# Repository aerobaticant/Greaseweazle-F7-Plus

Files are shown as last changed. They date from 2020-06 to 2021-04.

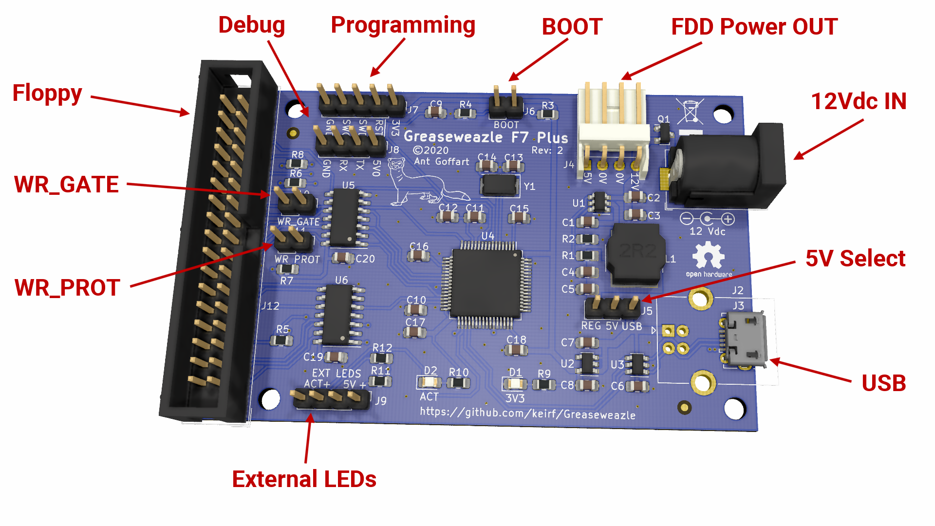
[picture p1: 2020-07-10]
Greaseweazle_F7_Plus_V2_White_Labelled.png

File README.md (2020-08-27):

# Greaseweazle-F7-Plus
My board design for [Keir Fraser's Greaseweazle](https://github.com/keirf/Greaseweazle).

The differences between this design and the original F7 are:

  * PCB 80mm x 50mm, KryoFlux form factor.
  * Added stronger buffers for driving 5.25" drives with higher current pull-up resistors.
  * Integrated 5V switching regulator, so only a single 12V supply is required for drives needing both rails.
  * Choice of full-size or micro USB connector.
  * USB ESD (electro-static discharge) protection.
  * Connections for external LEDs, for use if fitting the board in an enclosure.
  * Jumper link to select write protection by default.
  * Jumper link to disconnect WR_GATE for physical hardware level write protection.

This repository has only just been created.

Please check out the [Wiki](https://github.com/aerobaticant/Greaseweazle-F7-Plus/wiki) (under construction).

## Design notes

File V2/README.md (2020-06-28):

This is the folder containing the source files for my Greaseweazle V2 Plus board

Please note that this design is released using the Open Hardware licence.
https://www.oshwa.org/definition/

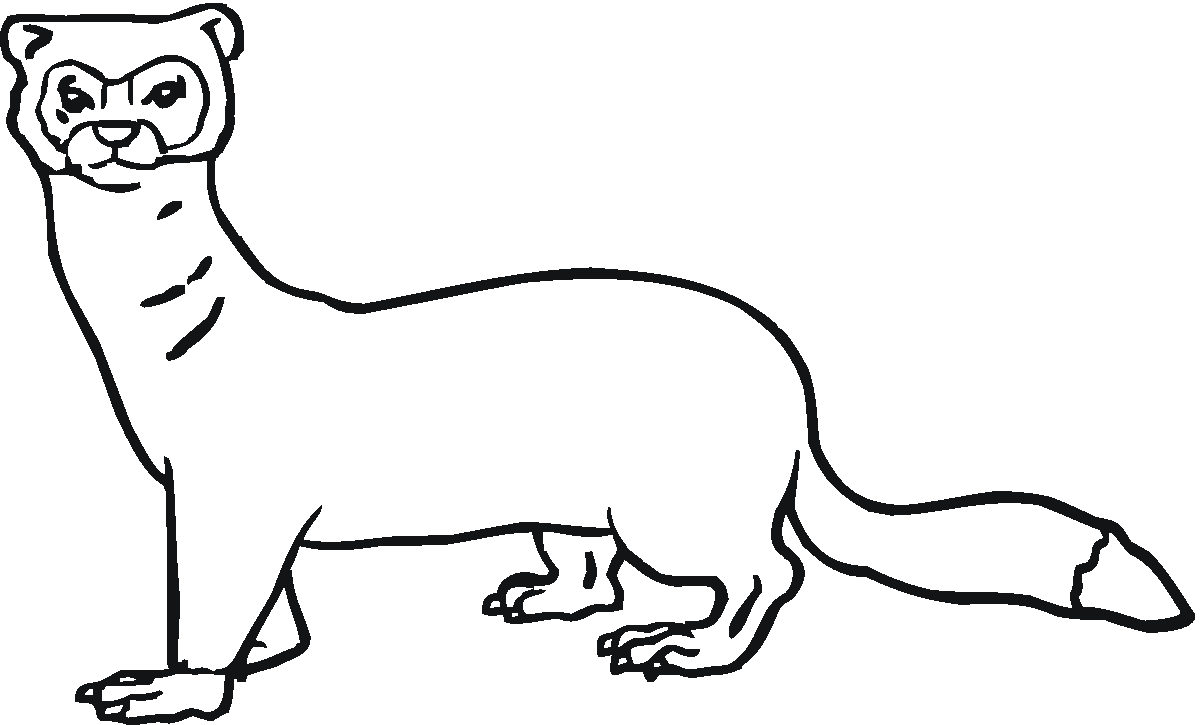
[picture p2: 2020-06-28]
V2/weasle_clipart.png

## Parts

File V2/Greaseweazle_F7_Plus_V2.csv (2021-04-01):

Source: | C:\Projects\KiCad\Greaseweazle_F7_Plus_V2\Greaseweazle_F7_Plus_V2.sch
Date: | 18/06/2020 10:20:13
Tool: | Eeschema (5.1.5)-3
Generator: | C:\Program Files\KiCad\bin\scripting\plugins/bom_csv_grouped_by_value.py
Component Count: | 62
Individual Components:
Item | Qty | Reference(s) | Value | LibPart | Footprint | Datasheet
 |  | C1 | 100N | Device:C_Small | Capacitor_SMD:C_0805_2012Metric_Pad1.15x1.40mm_HandSolder | ~
 |  | C2 | 10U | Device:C_Small | Capacitor_SMD:C_0805_2012Metric_Pad1.15x1.40mm_HandSolder | ~
 |  | C3 | 10U | Device:C_Small | Capacitor_SMD:C_0805_2012Metric_Pad1.15x1.40mm_HandSolder | ~
 |  | C4 | 22U | Device:C_Small | Capacitor_SMD:C_0805_2012Metric_Pad1.15x1.40mm_HandSolder | ~
 |  | C5 | 22U | Device:C_Small | Capacitor_SMD:C_0805_2012Metric_Pad1.15x1.40mm_HandSolder | ~
 |  | C6 | 100N | Device:C_Small | Capacitor_SMD:C_0805_2012Metric_Pad1.15x1.40mm_HandSolder | ~
 |  | C7 | 1U0 | Device:C_Small | Capacitor_SMD:C_0805_2012Metric_Pad1.15x1.40mm_HandSolder | ~
 |  | C8 | 1U0 | Device:C_Small | Capacitor_SMD:C_0805_2012Metric_Pad1.15x1.40mm_HandSolder | ~
 |  | C9 | 100N | Device:C_Small | Capacitor_SMD:C_0805_2012Metric_Pad1.15x1.40mm_HandSolder | ~
 |  | C10 | 10U | Device:C_Small | Capacitor_SMD:C_0805_2012Metric_Pad1.15x1.40mm_HandSolder | ~
 |  | C11 | 1U0 | Device:C_Small | Capacitor_SMD:C_0805_2012Metric_Pad1.15x1.40mm_HandSolder | ~
 |  | C12 | 100N | Device:C_Small | Capacitor_SMD:C_0805_2012Metric_Pad1.15x1.40mm_HandSolder | ~
 |  | C13 | 27P | Device:C_Small | Capacitor_SMD:C_0805_2012Metric_Pad1.15x1.40mm_HandSolder | ~
 |  | C14 | 27P | Device:C_Small | Capacitor_SMD:C_0805_2012Metric_Pad1.15x1.40mm_HandSolder | ~
 |  | C15 | 100N | Device:C_Small | Capacitor_SMD:C_0805_2012Metric_Pad1.15x1.40mm_HandSolder | ~
 |  | C16 | 100N | Device:C_Small | Capacitor_SMD:C_0805_2012Metric_Pad1.15x1.40mm_HandSolder | ~
 |  | C17 | 100N | Device:C_Small | Capacitor_SMD:C_0805_2012Metric_Pad1.15x1.40mm_HandSolder | ~
 |  | C18 | 100N | Device:C_Small | Capacitor_SMD:C_0805_2012Metric_Pad1.15x1.40mm_HandSolder | ~
 |  | C19 | 100N | Device:C_Small | Capacitor_SMD:C_0805_2012Metric_Pad1.15x1.40mm_HandSolder | ~
 |  | C20 | 100N | Device:C_Small | Capacitor_SMD:C_0805_2012Metric_Pad1.15x1.40mm_HandSolder | ~
 |  | D1 | GREEN | Device:LED_Small | LED_SMD:LED_0805_2012Metric_Pad1.15x1.40mm_HandSolder | ~
 |  | D2 | GREEN | Device:LED_Small | LED_SMD:LED_0805_2012Metric_Pad1.15x1.40mm_HandSolder | ~
 |  | FID1 | Fiducial | Mechanical:Fiducial | Fiducial:Fiducial_1mm_Mask2mm | ~
 |  | FID2 | Fiducial | Mechanical:Fiducial | Fiducial:Fiducial_1mm_Mask2mm | ~
 |  | H1 | M3 | Mechanical:MountingHole | MountingHole:MountingHole_3mm | ~
 |  | H2 | M3 | Mechanical:MountingHole | MountingHole:MountingHole_3mm | ~
 |  | H3 | M3 | Mechanical:MountingHole | MountingHole:MountingHole_3mm | ~
 |  | H4 | M3 | Mechanical:MountingHole | MountingHole:MountingHole_3mm | ~
 |  | J1 | Wurth 694106301002 | Connector:Barrel_Jack_Switch | Connector_BarrelJack:BarrelJack_Horizontal | ~
 |  | J2 | USB_B | Connector:USB_B | Connector_USB:USB_B_OST_USB-B1HSxx_Horizontal | ~
 |  | J3 | Molex 105017-1001 | Connector:USB_B_Micro | Connector_USB:USB_Micro-B_Molex-105017-0001 | ~
 |  | J4 | TE EI 171826-4 | Connector_Generic:Conn_01x04 | AmberTronic:TE_171826-4_1x4_P2.50mm_Horizontal | ~
 |  | J5 | PIN1X3 | Connector_Generic:Conn_01x03 | Connector_PinHeader_2.54mm:PinHeader_1x03_P2.54mm_Vertical | ~
 |  | J6 | PIN1X2 | Connector_Generic:Conn_01x02 | Connector_PinHeader_2.54mm:PinHeader_1x02_P2.54mm_Vertical | ~
 |  | J7 | PIN1X5 | Connector_Generic:Conn_01x05 | Connector_PinHeader_2.54mm:PinHeader_1x05_P2.54mm_Vertical | ~
 |  | J8 | PIN1X4 | Connector_Generic:Conn_01x04 | Connector_PinHeader_2.54mm:PinHeader_1x04_P2.54mm_Vertical | ~
 |  | J9 | PIN1X4 | Connector_Generic:Conn_01x04 | Connector_PinHeader_2.54mm:PinHeader_1x04_P2.54mm_Vertical | ~
 |  | J10 | PIN1X2 | Connector_Generic:Conn_01x02 | Connector_PinHeader_2.54mm:PinHeader_1x02_P2.54mm_Vertical | ~
 |  | J11 | PIN1X2 | Connector_Generic:Conn_01x02 | Connector_PinHeader_2.54mm:PinHeader_1x02_P2.54mm_Vertical | ~
 |  | J12 | IDC Box Header | Connector_Generic:Conn_02x17_Odd_Even | Connector_IDC:IDC-Header_2x17_P2.54mm_Vertical | ~
 |  | L1 | SRN8040TA-4R7 | Device:L_Small | Inductor_SMD:L_Bourns_SRN8040TA | ~
 |  | LOGO1 | OSHW Logo | Graphic:Logo_Open_Hardware_Small | Symbol:OSHW-Logo2_7.3x6mm_SilkScreen | ~
 |  | Q1 | Si2393DS | Device:Q_PMOS_GSD | Package_TO_SOT_SMD:SOT-23 | ~
 |  | R1 | 54K9 | Device:R_Small | Resistor_SMD:R_0805_2012Metric_Pad1.15x1.40mm_HandSolder | ~
 |  | R2 | 10K0 | Device:R_Small | Resistor_SMD:R_0805_2012Metric_Pad1.15x1.40mm_HandSolder | ~
 |  | R3 | 1K0 | Device:R_Small | Resistor_SMD:R_0805_2012Metric_Pad1.15x1.40mm_HandSolder | ~
 |  | R4 | 10K0 | Device:R_Small | Resistor_SMD:R_0805_2012Metric_Pad1.15x1.40mm_HandSolder | ~
 |  | R5 | 1K0 | Device:R_Small | Resistor_SMD:R_0805_2012Metric_Pad1.15x1.40mm_HandSolder | ~
 |  | R6 | 1K0 | Device:R_Small | Resistor_SMD:R_0805_2012Metric_Pad1.15x1.40mm_HandSolder | ~
 |  | R7 | 1K0 | Device:R_Small | Resistor_SMD:R_0805_2012Metric_Pad1.15x1.40mm_HandSolder | ~
 |  | R8 | 1K0 | Device:R_Small | Resistor_SMD:R_0805_2012Metric_Pad1.15x1.40mm_HandSolder | ~
 |  | R9 | 330R | Device:R_Small | Resistor_SMD:R_0805_2012Metric_Pad1.15x1.40mm_HandSolder | ~
 |  | R10 | 330R | Device:R_Small | Resistor_SMD:R_0805_2012Metric_Pad1.15x1.40mm_HandSolder | ~
 |  | R11 | 560R | Device:R_Small | Resistor_SMD:R_0805_2012Metric_Pad1.15x1.40mm_HandSolder | ~
 |  | R12 | 560R | Device:R_Small | Resistor_SMD:R_0805_2012Metric_Pad1.15x1.40mm_HandSolder | ~
 |  | U1 | TPS562201DDC | Regulator_Switching:TPS562200 | Package_TO_SOT_SMD:SOT-23-6 | http://www.ti.com/lit/ds/symlink/tps563200.pdf
 |  | U2 | TLV75533PDBV | Regulator_Linear:TLV75533PDBV | Package_TO_SOT_SMD:SOT-23-5 | http://www.ti.com/lit/ds/symlink/tlv755p.pdf
 |  | U3 | USBLC6-2SC6 | Power_Protection:USBLC6-2SC6 | Package_TO_SOT_SMD:SOT-23-6 | http://www2.st.com/resource/en/datasheet/CD00050750.pdf
 |  | U4 | STM32F730R8T6 | MCU_ST_STM32F7:STM32F732RETx | Package_QFP:LQFP-64_10x10mm_P0.5mm | http://www.st.com/st-web-ui/static/active/en/resource/technical/document/datasheet/DM00330507.pdf
 |  | U5 | 74LS07 | 74xx:74LS07 | Package_SO:SOIC-14_3.9x8.7mm_P1.27mm | www.ti.com/lit/ds/symlink/sn74ls07.pdf
 |  | U6 | 74LS07 | 74xx:74LS07 | Package_SO:SOIC-14_3.9x8.7mm_P1.27mm | www.ti.com/lit/ds/symlink/sn74ls07.pdf
 |  | Y1 | 8.000MHz | Device:Crystal_Small | Crystal:Crystal_SMD_5032-2Pin_5.0x3.2mm | ~
Collated Components:
Item | Qty | Reference(s) | Value | LibPart | Footprint | Datasheet
1 | 10 | C1, C6, C9, C12, C15, C16, C17, C18, C19, C20 | 100N | Device:C_Small | Capacitor_SMD:C_0805_2012Metric_Pad1.15x1.40mm_HandSolder | ~
2 | 3 | C2, C3, C10 | 10U | Device:C_Small | Capacitor_SMD:C_0805_2012Metric_Pad1.15x1.40mm_HandSolder | ~
3 | 2 | C4, C5 | 22U | Device:C_Small | Capacitor_SMD:C_0805_2012Metric_Pad1.15x1.40mm_HandSolder | ~
4 | 3 | C7, C8, C11 | 1U0 | Device:C_Small | Capacitor_SMD:C_0805_2012Metric_Pad1.15x1.40mm_HandSolder | ~
5 | 2 | C13, C14 | 27P | Device:C_Small | Capacitor_SMD:C_0805_2012Metric_Pad1.15x1.40mm_HandSolder | ~
6 | 2 | D1, D2 | GREEN | Device:LED_Small | LED_SMD:LED_0805_2012Metric_Pad1.15x1.40mm_HandSolder | ~
7 | 2 | FID1, FID2 | Fiducial | Mechanical:Fiducial | Fiducial:Fiducial_1mm_Mask2mm | ~
8 | 4 | H1, H2, H3, H4 | M3 | Mechanical:MountingHole | MountingHole:MountingHole_3mm | ~
9 | 1 | J1 | Wurth 694106301002 | Connector:Barrel_Jack_Switch | Connector_BarrelJack:BarrelJack_Horizontal | ~
10 | 1 | J2 | USB_B | Connector:USB_B | Connector_USB:USB_B_OST_USB-B1HSxx_Horizontal | ~
11 | 1 | J3 | Molex 105017-1001 | Connector:USB_B_Micro | Connector_USB:USB_Micro-B_Molex-105017-0001 | ~
12 | 1 | J4 | TE EI 171826-4 | Connector_Generic:Conn_01x04 | AmberTronic:TE_171826-4_1x4_P2.50mm_Horizontal | ~
13 | 1 | J5 | PIN1X3 | Connector_Generic:Conn_01x03 | Connector_PinHeader_2.54mm:PinHeader_1x03_P2.54mm_Vertical | ~
14 | 3 | J6, J10, J11 | PIN1X2 | Connector_Generic:Conn_01x02 | Connector_PinHeader_2.54mm:PinHeader_1x02_P2.54mm_Vertical | ~
15 | 1 | J7 | PIN1X5 | Connector_Generic:Conn_01x05 | Connector_PinHeader_2.54mm:PinHeader_1x05_P2.54mm_Vertical | ~
16 | 2 | J8, J9 | PIN1X4 | Connector_Generic:Conn_01x04 | Connector_PinHeader_2.54mm:PinHeader_1x04_P2.54mm_Vertical | ~
17 | 1 | J12 | IDC Box Header | Connector_Generic:Conn_02x17_Odd_Even | Connector_IDC:IDC-Header_2x17_P2.54mm_Vertical | ~
18 | 1 | L1 | SRN8040TA-4R7 | Device:L_Small | Inductor_SMD:L_Bourns_SRN8040TA | ~
19 | 1 | LOGO1 | OSHW Logo | Graphic:Logo_Open_Hardware_Small | Symbol:OSHW-Logo2_7.3x6mm_SilkScreen | ~
20 | 1 | Q1 | Si2393DS | Device:Q_PMOS_GSD | Package_TO_SOT_SMD:SOT-23 | ~
21 | 1 | R1 | 54K9 | Device:R_Small | Resistor_SMD:R_0805_2012Metric_Pad1.15x1.40mm_HandSolder | ~
22 | 2 | R2, R4 | 10K0 | Device:R_Small | Resistor_SMD:R_0805_2012Metric_Pad1.15x1.40mm_HandSolder | ~
23 | 5 | R3, R5, R6, R7, R8 | 1K0 | Device:R_Small | Resistor_SMD:R_0805_2012Metric_Pad1.15x1.40mm_HandSolder | ~
24 | 2 | R9, R10 | 330R | Device:R_Small | Resistor_SMD:R_0805_2012Metric_Pad1.15x1.40mm_HandSolder | ~
25 | 2 | R11, R12 | 560R | Device:R_Small | Resistor_SMD:R_0805_2012Metric_Pad1.15x1.40mm_HandSolder | ~
26 | 1 | U1 | TPS562201DDC | Regulator_Switching:TPS562200 | Package_TO_SOT_SMD:SOT-23-6 | http://www.ti.com/lit/ds/symlink/tps563200.pdf
27 | 1 | U2 | TLV75533PDBV | Regulator_Linear:TLV75533PDBV | Package_TO_SOT_SMD:SOT-23-5 | http://www.ti.com/lit/ds/symlink/tlv755p.pdf
28 | 1 | U3 | USBLC6-2SC6 | Power_Protection:USBLC6-2SC6 | Package_TO_SOT_SMD:SOT-23-6 | http://www2.st.com/resource/en/datasheet/CD00050750.pdf
29 | 1 | U4 | STM32F730R8T6 | MCU_ST_STM32F7:STM32F732RETx | Package_QFP:LQFP-64_10x10mm_P0.5mm | http://www.st.com/st-web-ui/static/active/en/resource/technical/document/datasheet/DM00330507.pdf
30 | 2 | U5, U6 | 74LS07 | 74xx:74LS07 | Package_SO:SOIC-14_3.9x8.7mm_P1.27mm | www.ti.com/lit/ds/symlink/sn74ls07.pdf
31 | 1 | Y1 | 8.000MHz | Device:Crystal_Small | Crystal:Crystal_SMD_5032-2Pin_5.0x3.2mm | ~

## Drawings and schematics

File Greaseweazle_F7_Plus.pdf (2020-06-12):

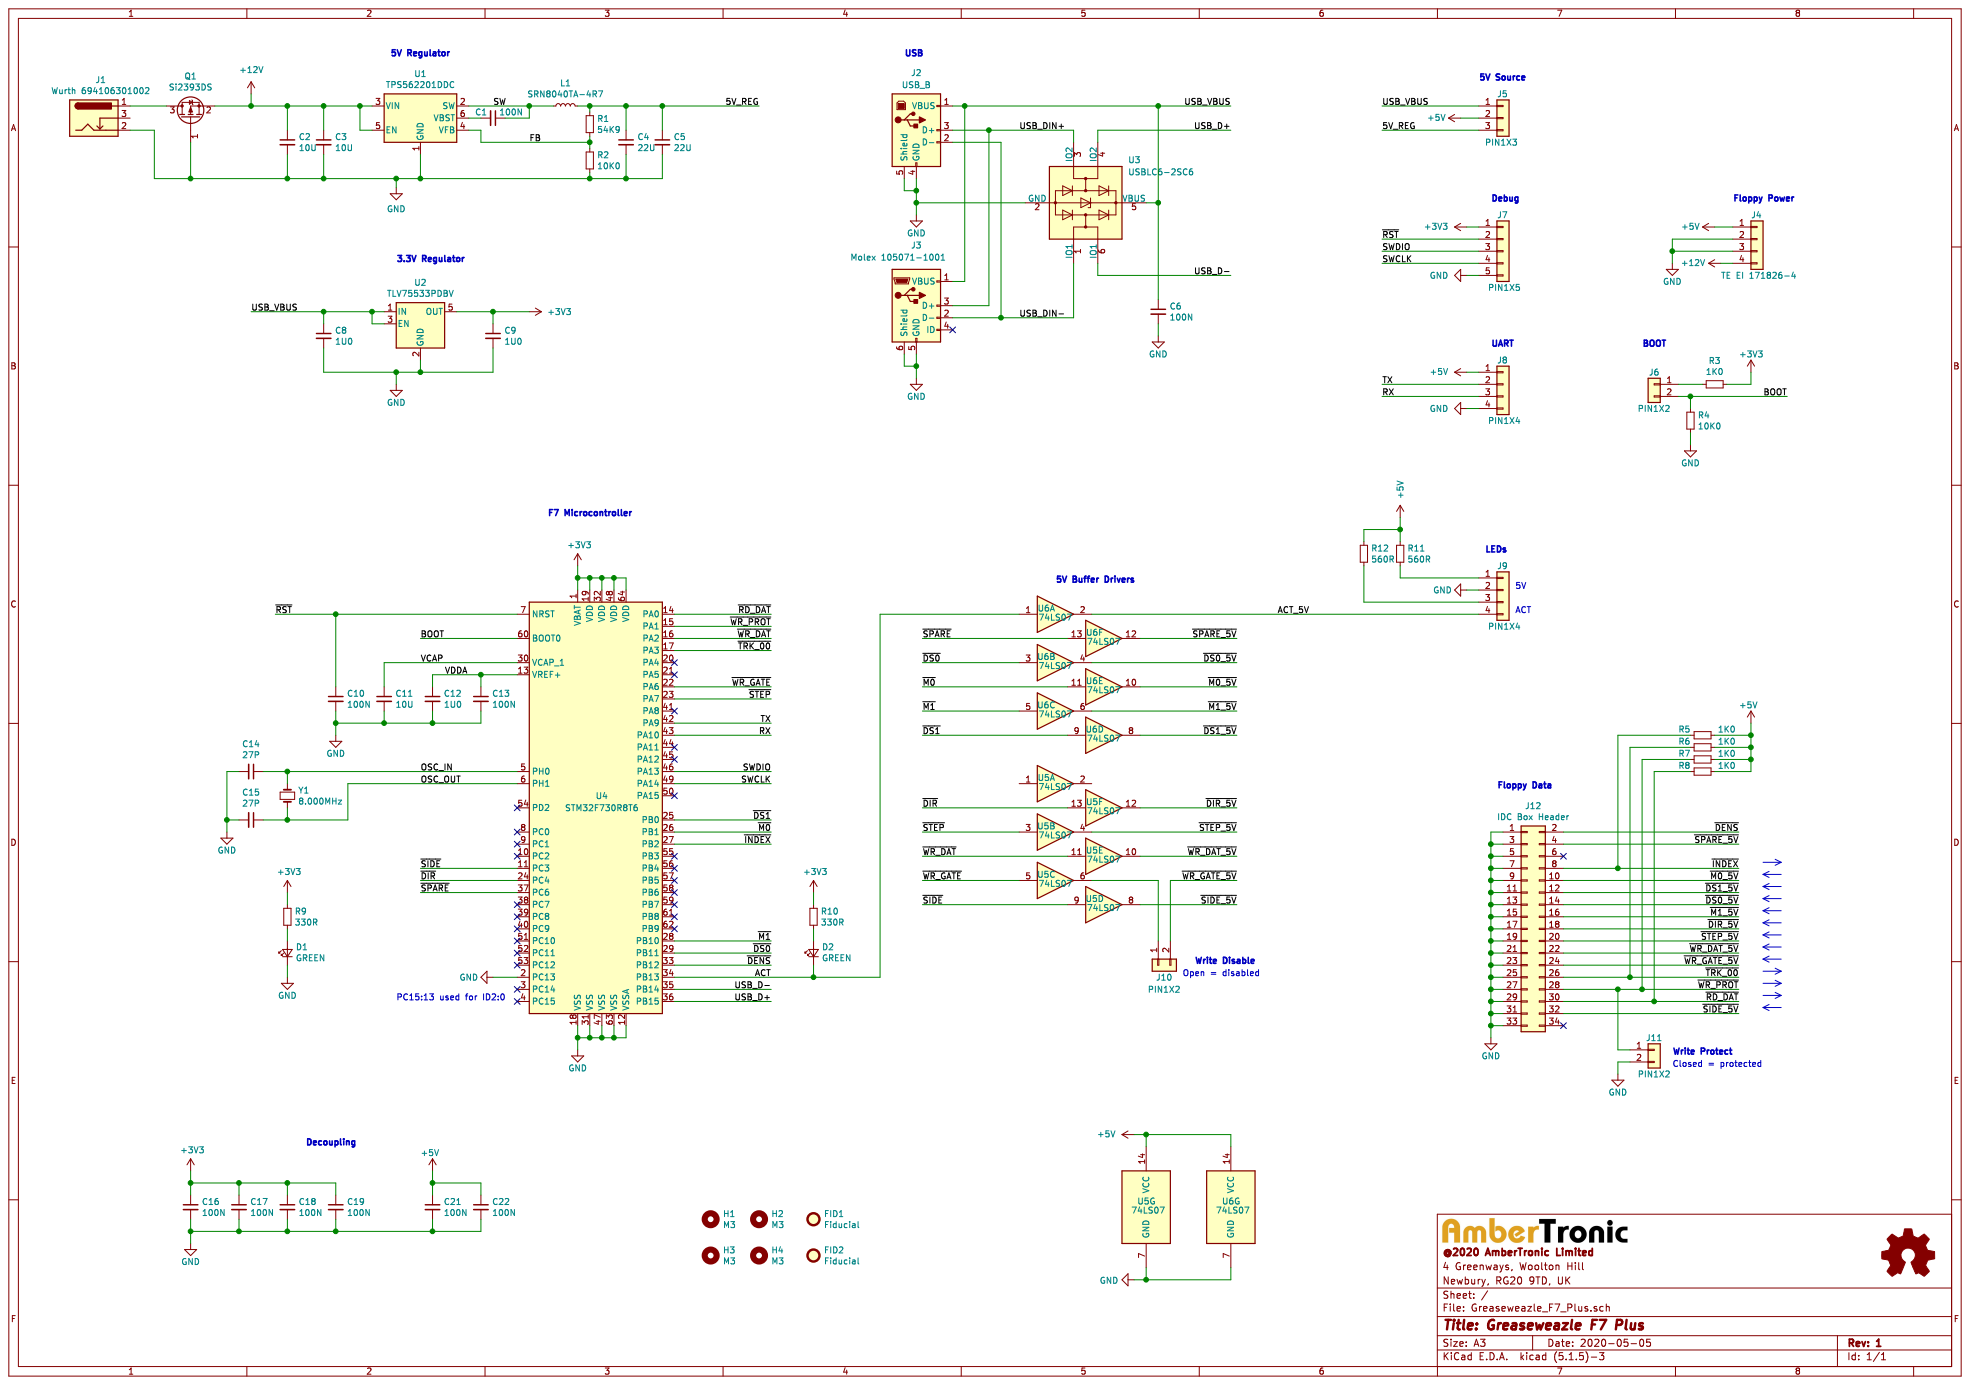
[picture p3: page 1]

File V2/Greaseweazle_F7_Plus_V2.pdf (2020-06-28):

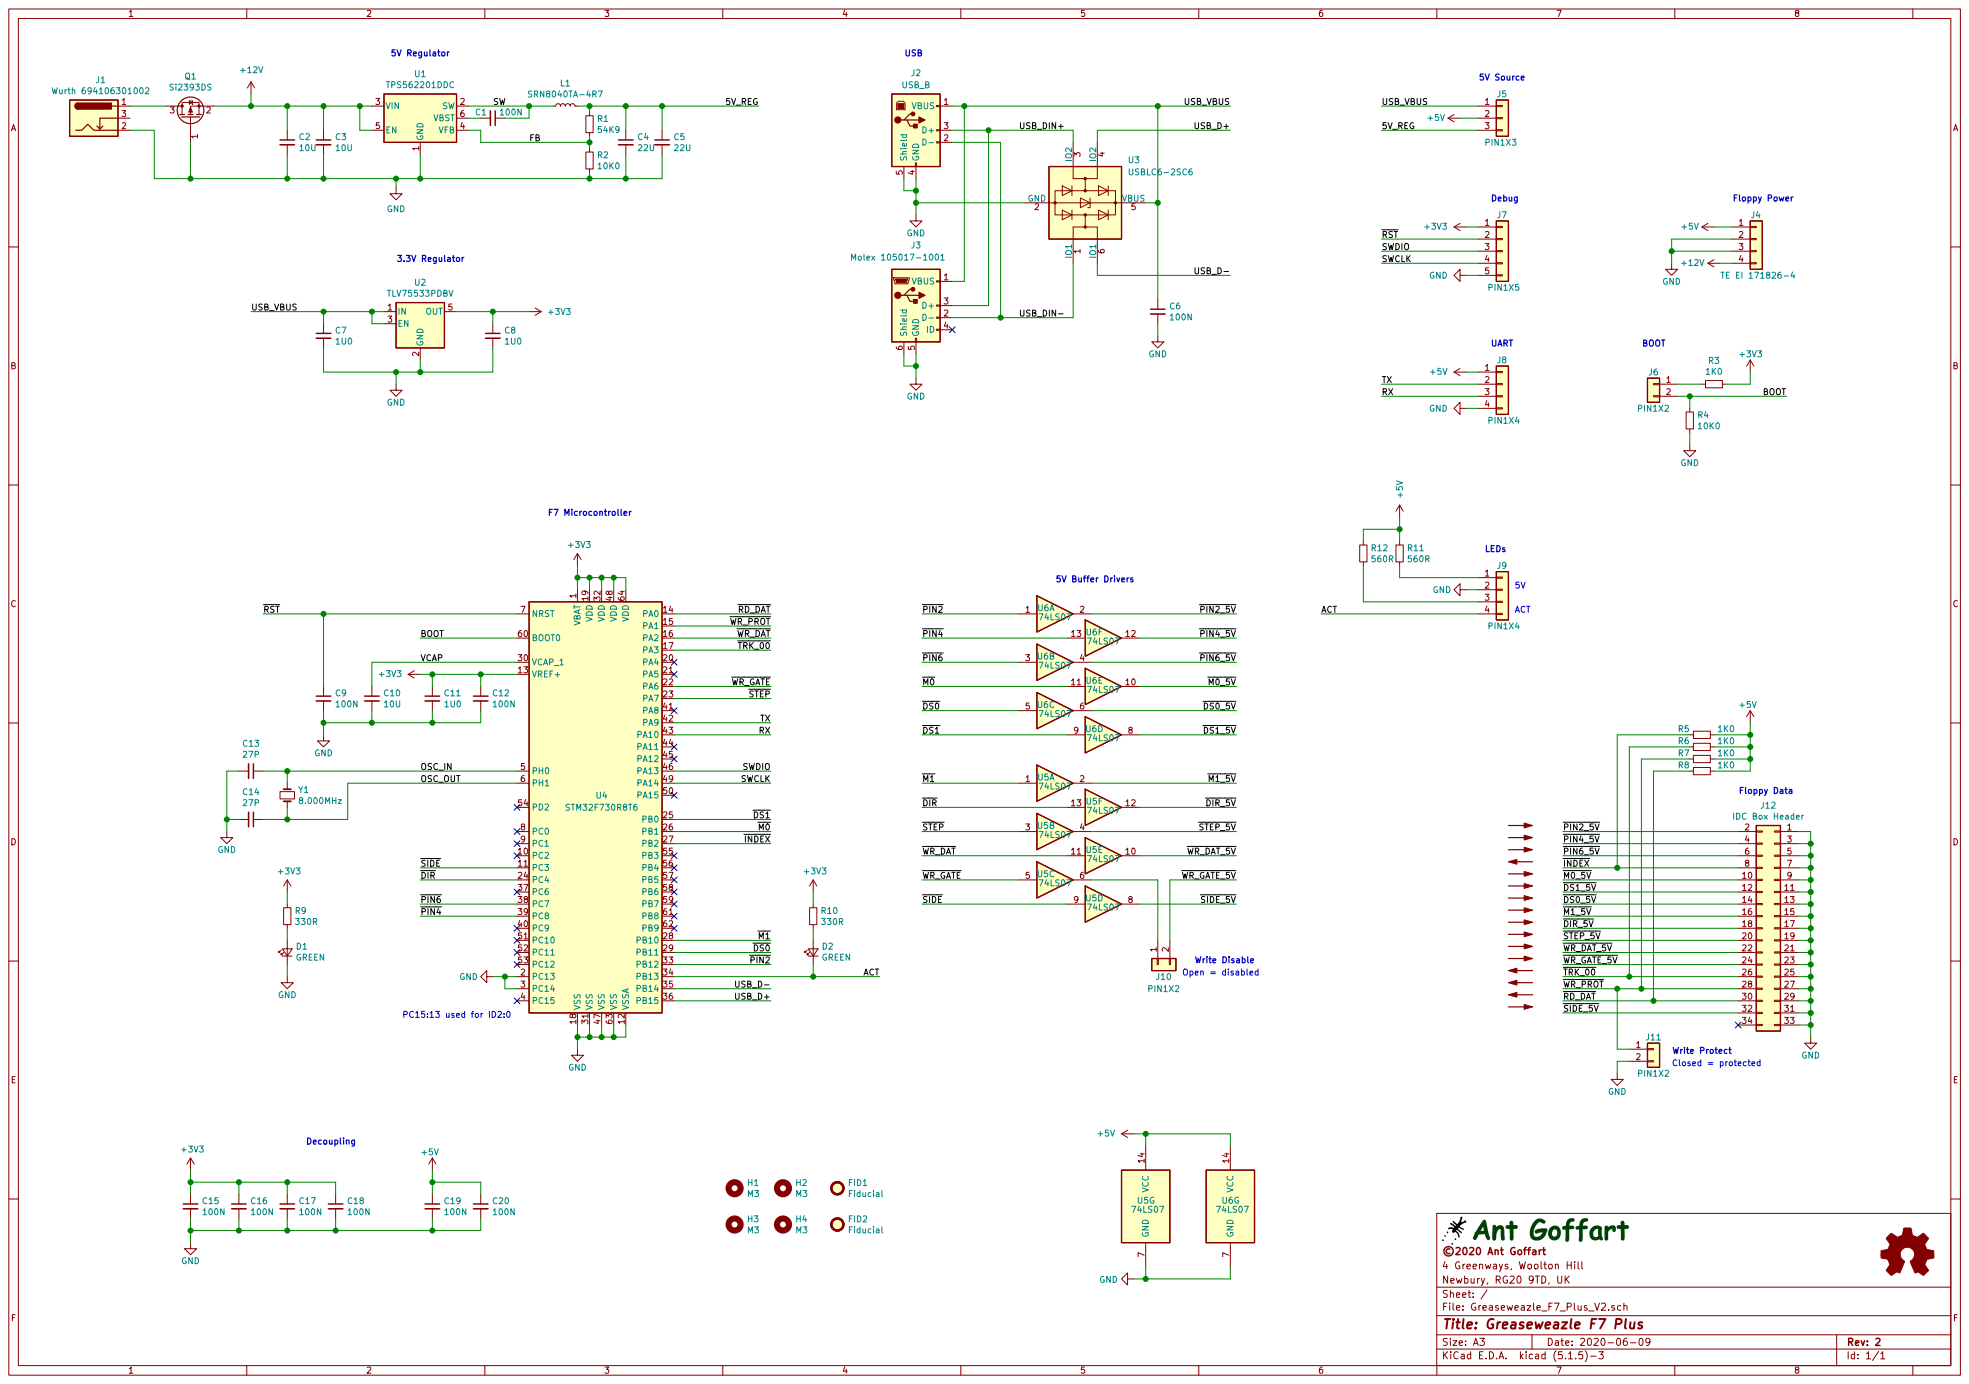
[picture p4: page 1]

16 | 15
18 | 17
20
22 | 21
24 | 23
26 | 25
28 | 27

File: Greaseweazle_F7_Plus_V2.sch Sheet: / ©2020 Ant Goffart 4 Greenways, Woolton Hill

Id: 1/1 Title: Greaseweazle F7 Plus

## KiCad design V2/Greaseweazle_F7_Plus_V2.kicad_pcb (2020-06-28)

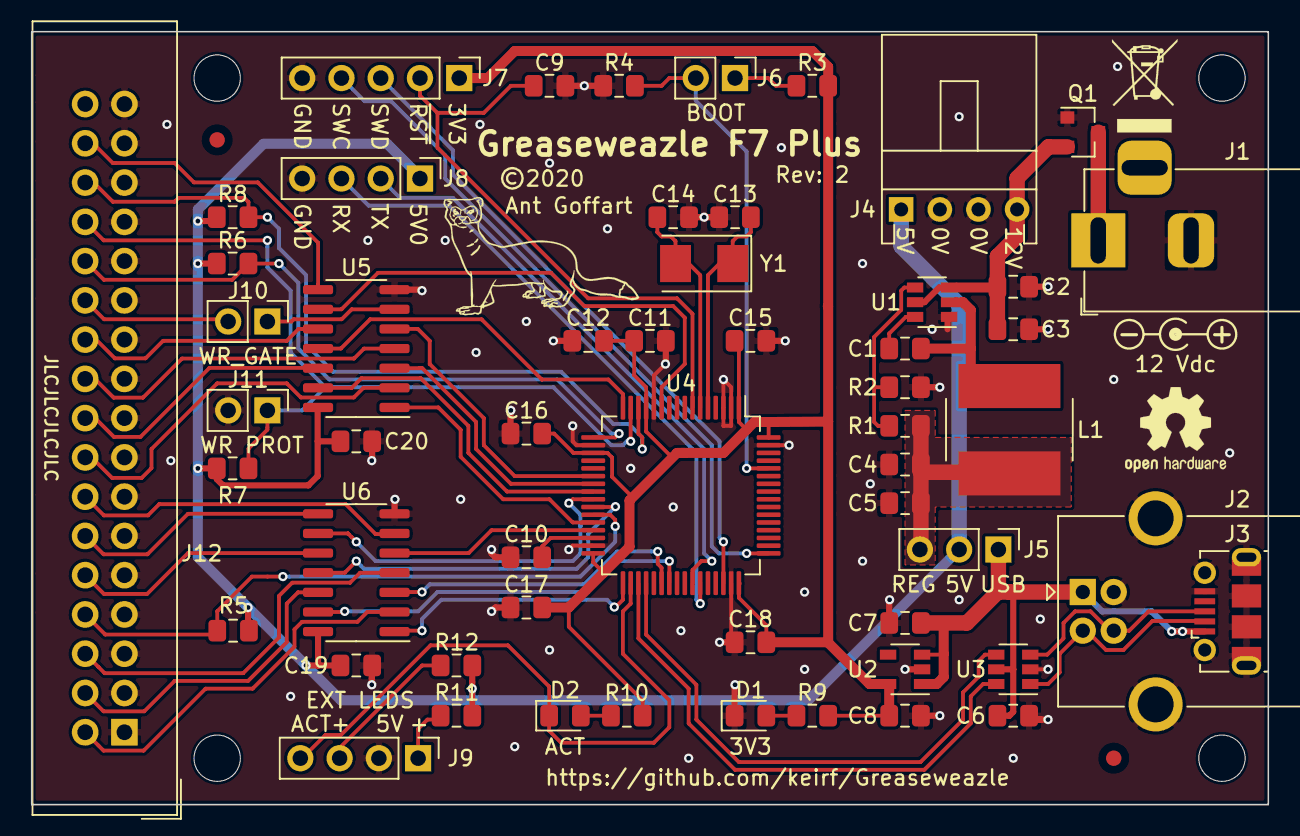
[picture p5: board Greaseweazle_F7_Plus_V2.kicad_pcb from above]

Board: 2 copper layers, 80.0 x 50.0 mm, 65 parts (0 on the bottom side), 58 nets.

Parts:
C1, C6, C9, C12, C15, C16, C17, C18, C19, C20: 100N; C_0805_2012Metric_Pad1.15x1.40mm_HandSolder
C2, C3, C10: 10U; C_0805_2012Metric_Pad1.15x1.40mm_HandSolder
C4, C5: 22U; C_0805_2012Metric_Pad1.15x1.40mm_HandSolder
C7, C8, C11: 1U0; C_0805_2012Metric_Pad1.15x1.40mm_HandSolder
C13, C14: 27P; C_0805_2012Metric_Pad1.15x1.40mm_HandSolder
D1, D2: GREEN; LED_0805_2012Metric_Pad1.15x1.40mm_HandSolder
FID1, FID2: Fiducial; Fiducial_1mm_Mask2mm
G**: WEEE-Logo_4.2x6mm_SilkScreen
G**#2: Symbol_Barrel_Polarity
G**#3: Weasle; WeasleLogo
H1, H2, H3, H4: M3; MountingHole_3mm
J1: Wurth 694106301002; BarrelJack_Horizontal
J2: USB_B; USB_B_OST_USB-B1HSxx_Horizontal
J3: Molex 105017-1001; USB_Micro-B_Molex-105017-0001
J4: TE EI 171826-4; TE_171826-4_1x4_P2.50mm_Horizontal
J5: PIN1X3; PinHeader_1x03_P2.54mm_Vertical
J6, J10, J11: PIN1X2; PinHeader_1x02_P2.54mm_Vertical
J7: PIN1X5; PinHeader_1x05_P2.54mm_Vertical
J8, J9: PIN1X4; PinHeader_1x04_P2.54mm_Vertical
J12: IDC Box Header; IDC-Header_2x17_P2.54mm_Vertical
L1: SRN8040TA-4R7; L_Bourns_SRN8040TA
LOGO1: OSHW Logo; OSHW-Logo2_7.3x6mm_SilkScreen
Q1: Si2393DS; SOT-23
R1: 54K9; R_0805_2012Metric_Pad1.15x1.40mm_HandSolder
R2, R4: 10K0; R_0805_2012Metric_Pad1.15x1.40mm_HandSolder
R3, R5, R6, R7, R8: 1K0; R_0805_2012Metric_Pad1.15x1.40mm_HandSolder
R9, R10: 330R; R_0805_2012Metric_Pad1.15x1.40mm_HandSolder
R11, R12: 560R; R_0805_2012Metric_Pad1.15x1.40mm_HandSolder
U1: TPS562201DDC; SOT-23-6
U2: TLV75533PDBV; SOT-23-5
U3: USBLC6-2SC6; SOT-23-6
U4: STM32F730R8T6; LQFP-64_10x10mm_P0.5mm
U5, U6: 74LS07; SOIC-14_3.9x8.7mm_P1.27mm
Y1: 8.000MHz; Crystal_SMD_5032-2Pin_5.0x3.2mm

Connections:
+3V3: C8.1, C11.1, C12.1, C15.1, C16.1, C17.1, C18.1, J7.1, R3.1, R9.1, R10.1, U2.5, U4.1, U4.13, U4.19, U4.32, U4.48, U4.64
+5V: C19.1, C20.1, J4.1, J5.2, J8.1, R5.1, R6.1, R7.1, R8.1, R11.1, R12.1, U5.14, U6.14
+12V: C2.1, C3.1, J4.4, Q1.2, U1.3, U1.5
/5V_REG: C4.1, C5.1, J5.3, L1.2, R1.1
/ACT: D2.1, J9.4, U4.34
/BOOT: J6.2, R4.1, U4.60
/FB: R1.2, R2.1, U1.4
/OSC_IN: C13.1, U4.5, Y1.1
/OSC_OUT: C14.1, U4.6, Y1.2
/RX: J8.3, U4.43
/SW: C1.1, L1.1, U1.2
/SWCLK: J7.4, U4.49
/SWDIO: J7.3, U4.46
/TX: J8.2, U4.42
/USB_D+: U3.4, U4.36
/USB_D-: U3.6, U4.35
/USB_DIN+: J2.3, J3.3, U3.3
/USB_DIN-: J2.2, J3.2, U3.1
/USB_VBUS: C6.1, C7.1, J2.1, J3.1, J5.1, U2.1, U2.3, U3.5
/VCAP: C10.1, U4.30
/~DIR_5V~: J12.18, U5.12
/~DIR~: U4.24, U5.13
/~DS0_5V~: J12.14, U6.6
/~DS0~: U4.29, U6.5
/~DS1_5V~: J12.12, U6.8
/~DS1~: U4.25, U6.9
/~INDEX~: J12.8, R5.2, U4.27
/~M0_5V~: J12.10, U6.10
/~M0~: U4.26, U6.11
/~M1_5V~: J12.16, U5.2
/~M1~: U4.28, U5.1
/~PIN2_5V~: J12.2, U6.2
/~PIN2~: U4.33, U6.1
/~PIN4_5V~: J12.4, U6.12
/~PIN4~: U4.39, U6.13
/~PIN6_5V~: J12.6, U6.4
/~PIN6~: U4.38, U6.3
/~RD_DAT~: J12.30, R8.2, U4.14
/~RST~: C9.1, J7.2, U4.7
/~SIDE_5V~: J12.32, U5.8
/~SIDE~: U4.11, U5.9
/~STEP_5V~: J12.20, U5.4
/~STEP~: U4.23, U5.3
/~TRK_00~: J12.26, R6.2, U4.17
/~WR_DAT_5V~: J12.22, U5.10
/~WR_DAT~: U4.16, U5.11
/~WR_GATE_5V~: J10.2, J12.24
/~WR_GATE~: U4.22, U5.5
/~WR_PROT~: J11.1, J12.28, R7.2, U4.15
GND: C2.2, C3.2, C4.2, C5.2, C6.2, C7.2, C8.2, C9.2, C10.2, C11.2, C12.2, C13.2, C14.2, C15.2, C16.2, C17.2, C18.2, C19.2, C20.2, D1.1, J1.2, J2.4, J2.5, J3.5, J3.6, J4.2, J4.3, J7.5, J8.4, J9.2, J11.2, J12.1, J12.3, J12.5, J12.7, J12.9, J12.11, J12.13, J12.15, J12.17, J12.19, J12.21, J12.23, J12.25, J12.27, J12.29, J12.31, J12.33, Q1.1, R2.2, R4.2, U1.1, U2.2, U3.2, U4.2, U4.3, U4.12, U4.18, U4.31, U4.47, U4.63, U5.7, U6.7
unnamed: C1.2, U1.6
unnamed: D1.2, R9.2
unnamed: D2.2, R10.2
unnamed: J1.1, Q1.3
unnamed: J6.1, R3.2
unnamed: J9.1, R11.2
unnamed: J9.3, R12.2
unnamed: J10.1, U5.6

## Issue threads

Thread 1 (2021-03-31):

BOM file

badass-boss, 2021-03-31:
Where is the BOM file for this board?? I can't find it anywhere. Please reply. Thanks in advance

sean-skt, 2021-03-31:
That's funny. I was just about the ask this question, when I logged in. I also just wanted to know, is it the BOM file that allows PCB manufacturers like JLCPCB to auto populate all SMT components on these boards when the manufacture them? JLCPCB apparently provides this service.
Thanks for this awesome project!!

aerobaticant, 2021-04-01:
If you open the project in KiCad you can use **Tools->Generate Bill of Materials** in Eeschema (schematic editor). All the part numbers are there.  I have now added the CSV file to the repo. :-)

Closed 2021-04-01.

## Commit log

2020-06-12 Added schematic and image
2020-06-28 Add all V2 files
    [Greaseweazle_F7_Plus_V2-B_Cu.gbr, Greaseweazle_F7_Plus_V2-B_Mask.gbr, Greaseweazle_F7_Plus_V2-Edge_Cuts.gbr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]
2021-04-01 Added CSV BOM file
    [Greaseweazle_F7_Plus_V2.csv]
